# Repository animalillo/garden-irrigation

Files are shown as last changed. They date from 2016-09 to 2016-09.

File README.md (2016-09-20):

#Garden Irrigation Control
This project was created as a fun learning experience for me with PICs (arduino dumilanove) and to solve tiny itch I had about my garden needing to set the analog clock it had to control irrigation times.

I migh or migh not update this project in the future with new features, and I will be creating a side project to control this system from a phone with or without a server web interface to gather the data, that's yet to be seen.

Of course this system  could have many other uses besides irrigation control. Basically any timed electrical switching could be handled with this.
Hacking this code to use the sensor data to perform actions based on the sensor output shoulnd't be too hard. I might do that in the future, or maybe adding an earth humidity sensor and performing actions inresponse to that, i might do that some day.

###Features:
Right now the hardware consists on an arduino, ethernet shield + micro SD card reader, an RTC module that happens to have both, RTC and EEPROM ICs and an humidity sensor that has built-in thermometer.

- It logs the temperature and humidity to an sd file.
- Loads the network configuration from a file called net.cfg on the root of the micro SD card.
- Controls two relays with 4 on-off alarms consisting on an start and end time (HH:MM:SS).
- Exposes a serie of HTTP APIs to the connected network that allows log download, relay control, date and time configuration and instant sensor and status information access.

#Hardware
- Arduino UNO or compatible board
- HanRun Ethernet shield with Micro SD card reader
- I2C RTC module (Tiny RTC) obtained from [here](http://www.dx.com/p/tiny-rtc-real-time-clock-module-for-arduino-red-161172) which consists on:
-- DS1307 RTC chip
-- Atmel AT24C32 EEPROM 32K chip
- Kyees funduino ver: 2R1B relay module from [here](http://www.dx.com/p/arduino-2-channel-relay-shield-module-red-144140)

###Hardware setup:
The ethernet module is simply attached to the arduino board on the standard way.
As some of the pins are used by the ethernet shield, I used the next ones to connect the relay inputs to the arduino digital pins 8 and 9 outputs (IN1 -> digital 9, IN2 - digital 8).
As for the DHT11 (humidity sensor) I used the pin 7.
The I2C RTC clock SDA goes to Arduino analog pin 4 and the SCL goes to arduino analog pin 5 ([if you decide to use another arduino board you should change according to the arduino documentation](https://www.arduino.cc/en/Reference/Wire))

#Configuring network:
To configure the network on the device, you must place a file like the provded net.cfg.example file called net.cfg on the root directory of your sd card.
You must follow the next rules:

	MAC ADDRESS  that will use the device
    IP ADDRESS that will have the device on your network
    NETMASK of the network
    GATEWAY of the network
    DNS SERVER of the network
    
This is an example of a working NET.CFG file:

	DE:AD:BE:EF:FE:ED
	192.168.4.6
	255.255.255.0
	192.168.4.1
	192.168.4.1

#HTTP API
Last, but not least, the HTTP API:
All the date and time API endpoints will use the following format due to hardware limitations and code simplicity:
> YEAR/MONTH/DAY/DAY_OF_WEEK/HOUR/MINUTE/SECOND

- Date
	- **setTime** Configures the RTC clock with the given date and time.
    > 	http://ip_address/setTime/YEAR/MONTH/DAY/DAY_OF_WEEK/HOUR/MINUTE/SECOND

	> Example:
	> http://192.168.4.6/setTime/2016/09/20/2/17/29/30 would set the time and date to tuesday 20th of september of the year 2016 and the time to 17:29:30

	- **getTimes** Prints a plain text dump of the current date and time and the configured alarms.

- Alarms:
	- There is a total of 8 defined alarms, 4 for the each relay. Each alarm consists  on two times in between which the relay will be active, so it's important to **set them both!** There is no specific api to disable an alarm, but if you need to the procedure it's simple: set the start and end time to the same and it shouldn't fire.
	- All the alarm configurations are saved on the EEPROM and persisted in case of power failure.
	- **setAlarm** Configures an alarm.
		- This endpoint has three parameters, the alarm number, the operation type (start/stop) and the time.
		- The date part specified on this api will be ignored, but it's requiered.
	- >		http://ip_address/setAlarm/ALARM_NUMBER(1-8)/ALARM_MODE(start/stop)/DATE_AND_TIME_URL_FORMATTED
	 > Example:
	 > http://192.168.4.6/setAlarm/1/start/2016/09/20/2/17/29/30 **AND another call to** http://192.168.4.6/setAlarm/1/start/2016/09/20/2/19/00/00 would configure an alarm to start everyday at 17:19:30 and stop at 19:00:00

- Direct relay control
	- To control the relays two endpoints are available (sw1 and sw2), both have the same functionality: manually enabling, dissabling and controlling the relays.
	- **sw*X*** Access switch ***X***, replace X with 1 or 2.
		- **on** Turn the relay on.
		- **off** Turn the relay off.
			- **force** Force the relay to stay in off state even if an alarm would fire. This will be saved even after device restart and until the next call to on or off endpoints is made.
    - > Example:
     http://192.168.4.6/sw1/on Would turn the first relay on
     http://192.168.4.6/sw1/off Would turn the first relay off and let alarms fire
     http://192.168.4.6/sw1/off/force Would rutn the first relay off and prevent alarms from turning it on.

- Logs
	- To gather the logs that the system has generated a simple call to /log is needed. Note that the data log will be deleted once the transfer has finished.
	- **log** Get the logs and clear the file
	- The log format is a line containing each measurement, each line is confirmed of the current date and time and the sensors data
	- Example output:
	- 	> <2016-09-20 20:20:10>H:20;T:35;
		> <2016-09-20 20:21:10>H:21;T:34;
	- >		http://ip_address/log

	> Example:
	> http://192.168.4.6/log

- Sensors
	- **getSensors** Prints a simple line containing the sensors information and relay status. The format of the returned text is: sensor:status;other_sensor:status;...
		- **H** is an integer representing the relative humidity
		- **T** is an integer representing the temperature
		- **SW1** and **SW2** is an integer representing the boolean status of the relay 1 and 2

#Case
I made a simple 3D case, but the cap won't stick to the body unless you use tape, if anybody is willing to make a better design it's welcome, just make a merge request.

This case will work with the provided hardware specs, but I can't warrant that it will with another kind of module brands that might be perfectly compatible with this code as I designed it to be quiet a tight fit.
The case has space for a prototyping board and an extra board on top of this, so you can make a pretty circuit and integrate all the components.

I made the case so it's rain resistant, but that will depend on your 3D printer, material and printer configuration. Check the results that come from your printer!

#License
The code is under the [GPL V3](http://www.gnu.org/licenses/gpl.html) license created by Marcos Zuriaga, unless otherwise specified on the files.

The case model is under Creative Commons Attribution-NonCommercial-ShareAlike 4.0 International, also created by Marcos Zuriaga.

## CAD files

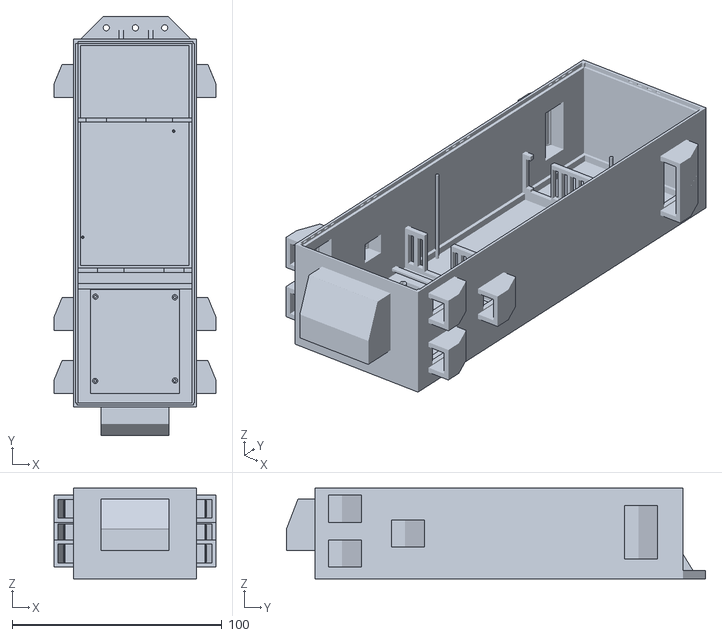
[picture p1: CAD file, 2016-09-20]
Case/garden_irrigation_system_body.stl
77.2 x 200.0 x 43.3

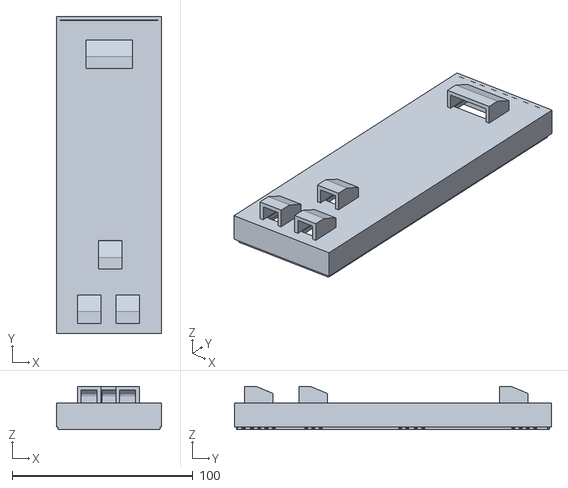
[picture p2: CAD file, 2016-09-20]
Case/garden_irrigation_system_cap.stl
58.4 x 175.5 x 23.9

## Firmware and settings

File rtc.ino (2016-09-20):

/* 
 * File:   DS1307.cpp
 * Version: 1.0
 * Purpose: Controlling relays, making them interact with time and 
 * log some sensor data while exposing some configuration and functions
 * trough the network.
 * License: GPL v3 (http://www.gnu.org/licenses/gpl.html)
 * Author: Marcos Zuriaga Miguel (Created on 04 of July 2016)
 */

/*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
  * You should have received a copy of the GNU General Public License
  * along with this program.  If not, see <http://www.gnu.org/licenses/>.
*/

#include <Wire.h>
#include <SD.h>
#include <Ethernet.h>
#include <avr/pgmspace.h>
#include <stdlib.h>

#include "lib/DHT11/DHT11.h"
#include "lib/DS1307/DS1307.h"
#include "lib/AT24C32_64/AT24C32_64.h"

#define DHT11_PIN 7
#define SW1 9
#define SW2 8

#define ALARM1_START_ADDRESS    0
#define ALARM2_START_ADDRESS    3
#define ALARM3_START_ADDRESS    6
#define ALARM4_START_ADDRESS    9

#define ALARM5_START_ADDRESS    12
#define ALARM6_START_ADDRESS    15
#define ALARM7_START_ADDRESS    18
#define ALARM8_START_ADDRESS    21

#define ALARM1_STOP_ADDRESS     24
#define ALARM2_STOP_ADDRESS     27
#define ALARM3_STOP_ADDRESS     30
#define ALARM4_STOP_ADDRESS     33

#define ALARM5_STOP_ADDRESS     36
#define ALARM6_STOP_ADDRESS     39
#define ALARM7_STOP_ADDRESS     42
#define ALARM8_STOP_ADDRESS     45

#define FORCE_SW1_OFF_ADDRESS   100
#define FORCE_SW2_OFF_ADDRESS   101

DS1307 rtc;
AT24C32_64 rom;

dht11 DHT11;
EthernetServer server(80);
unsigned long last_log = 0;
unsigned long last_tick = 0;
bool force_sw1_on = false;
bool force_sw2_on = false;
bool force_sw1_off = false;
bool force_sw2_off = false;

void setup() {
  Wire.begin();

  Serial.begin(9600);
  
  if (!rtc.isStarted()){
      Serial.println(F("setting up RTC for first boot"));
      startClock();
  }

  if (!SD.begin(4)) {
    Serial.println(F("initialization failed!"));
  }
  
  force_sw1_off = rom.readBool(FORCE_SW1_OFF_ADDRESS);
  force_sw2_off = rom.readBool(FORCE_SW2_OFF_ADDRESS);
  
  pinMode(SW1, OUTPUT);
  pinMode(SW2, OUTPUT);
  
  setupEthernet();
  
  Serial.println(F("ready"));
}

void loop() {
  DateTime t = rtc.getTime();
  while (DHT11.read(DHT11_PIN) != 0) delay(50);

//  DHT11.read(DHT11_PIN);
//  Serial.print(F("humidity:"));
//  Serial.println(DHT11.humidity);
//  Serial.print(F("temperature"));
//  Serial.println(DHT11.temperature);
  
  /*Serial.print(t.hour());Serial.print(":");Serial.print(t.minute());Serial.print(":");Serial.println(t.second());
  Serial.print("Day of the week: "); Serial.println(t.dayOfWeek());
  Serial.print(t.year());Serial.print("-");Serial.print(t.month());Serial.print("-");Serial.println(t.day());
*/
  EthernetClient client = server.available();
  if (client){
    // an http request ends with a blank line
    while (client.connected()) {
      if (client.available()) {
        String method = readLine(&client);
        String line = "";
        while (line.charAt(line.length()-1) != '\n') {
          line = readLine(&client);
          Serial.println(line.c_str());
        }

        Serial.println(method.c_str());
        if (method.indexOf(F("/sw1")) > 0){
          if (method.indexOf(F("/on")) > 0) {
            force_sw1_on = true;
            force_sw1_off = false;
          }

          if (method.indexOf(F("/off")) > 0){
            force_sw1_on = false;
            force_sw1_off = false;

            if (method.indexOf(F("/force")) > 0){
                force_sw1_off = true;
            }
          }
          
          rom.write(force_sw1_off, FORCE_SW1_OFF_ADDRESS);
          
          http_ok_html(&client);

          client.println(method.c_str());
        }
        else if (method.indexOf(F("/sw2")) > 0){
          if (method.indexOf(F("/on")) > 0) {
            force_sw2_on = true;
            force_sw2_off = false;
          }

          if (method.indexOf(F("/off")) > 0){
            force_sw2_on = false;
            force_sw2_off = false;
            
            if (method.indexOf(F("/force")) > 0){
                force_sw2_off = true;
            }
            
          }
          
          rom.write(force_sw2_off, FORCE_SW2_OFF_ADDRESS);
            
          http_ok_html(&client);

          client.println(method.c_str());
        }
        else if (method.indexOf(F("/log")) > 0){
          http_ok_text(&client);
          
          File current_file = SD.open(F("/log/data.log"));
          dump_logs(&client, &current_file);
          current_file.close();
          SD.remove(F("/log/data.log"));
//          printDirectory(f, 0);
        }
        else if (method.indexOf(F("getSensors")) > 0){
            http_ok_text(&client);
            
            client.print(F("H:")); client.print(DHT11.humidity); client.print(F(";")); 
            client.print(F("T:")); client.print(DHT11.temperature); client.print(F(";"));
            client.print(F("SW1:"));client.print(checkSW1(&t));client.print(F(";"));
            client.print(F("SW2:")); client.print(checkSW2(&t)); client.println(F(";"));
        }
        else if (method.indexOf(F("setTime")) > 0){
            http_ok_html(&client);
            
            t = extractUrlDate(&method, method.indexOf(F("setTime")));
            rtc.setTime(t);
        }
        else if (method.indexOf(F("getTimes"))){
            http_ok_text(&client);
            
            client.print(F("Current:")); client.print(t.toString().c_str()); client.println(F(";"));
            
            byte start[3] = {0,0,0};
            byte stop[3] = {0,0,0};

            for (uint8_t i = 0; i < 8; i++){
                rom.readByteArray((byte*)&start, ALARM1_START_ADDRESS + i*3, 3);
                rom.readByteArray((byte*)&stop, ALARM1_STOP_ADDRESS   + i*3, 3);
                
                client.print(F("Alarm")); client.print(i +1); client.print(F(":"));
                for (uint8_t x = 0; x < 3; x++){
                    client.print(start[x]); //client.print(F(":")); client.print(start[1]); client.print(F(":")); client.print(start[2]);
                    if (x < 2) client.print(F(":"));
                }
                client.print(F(","));
                for (uint8_t x = 0; x < 3; x++){
                    client.print(stop[x]); //client.print(stop[0]); client.print(F(":")); client.print(stop[1]); client.print(F(":")); client.print(stop[2]);
                    if (x < 2) client.print(F(":"));
                }
                
                client.println(F(";"));
            }
        }
        else if (method.indexOf(F("setAlarm")) > 0){
            http_ok_html(&client);
            
            if (method.indexOf(F("start")) > 0){
                int tmp = method.indexOf(F("/start"));
                char c[1] = {' '};
                
                t = extractUrlDate(&method, tmp+1);
                
                c[0] = method[tmp -1];
                tmp = atoi(c);
                
                tmp = atoi(c);
                
                setAlarm(&t, ALARM1_START_ADDRESS + 3*(tmp-1));
            }
            
            if (method.indexOf(F("stop")) > 0){
                int tmp = method.indexOf(F("/stop"));
                char c[2] = {' '};
                
                t = extractUrlDate(&method, tmp+1);
                c[0] = method[tmp -1];

                tmp = atoi(c);

                setAlarm(&t, ALARM1_STOP_ADDRESS + 3*(tmp-1));
            }
        }
        else {
            http_ok_html(&client);
        }
        
        
          delay(1);
          client.stop();
      }
    }
  }
  
  t = rtc.getTime();
  
  if (millis() - last_tick >= 1000){
//      Serial.print(t.hour());Serial.print(F(":"));Serial.print(t.minute());Serial.print(F(":"));Serial.println(t.second());
//      if(force_sw1_off) Serial.println(F("SW1 off forced"));
      
      switch1(checkSW1(&t));
      switch2(checkSW2(&t));
      
      last_tick = millis();
  }

  // Log each minute
  if (millis() - last_log  >= 60000){

    String dir = F("/log");
    if (SD.mkdir(dir)){
      File current_file;
      dir += F("/data.log");
      current_file = SD.open(dir, FILE_WRITE);

      current_file.print(F("<")); current_file.print(t.toString().c_str()); current_file.print(F(">")); 
      current_file.print(F("H:")); current_file.print(DHT11.humidity); current_file.print(F(";")); 
      current_file.print(F("T:")); current_file.print(DHT11.temperature); current_file.println(F(";"));
      current_file.close();
      
      last_log = millis();
    }
  }
}

bool checkSW1(DateTime* t) {
    return (!force_sw1_off && fireAlarm(t, ALARM1_START_ADDRESS, ALARM1_STOP_ADDRESS, 4)) || force_sw1_on;
}
bool checkSW2(DateTime* t) {
    return (!force_sw2_off && fireAlarm(t, ALARM5_START_ADDRESS, ALARM5_STOP_ADDRESS, 4)) || force_sw2_on;
}

void http_ok(EthernetClient* client){
    client->println(F("HTTP/1.1 200 OK"));
}

void http_ok_html(EthernetClient* client){
    http_ok(client);
    client->println(F("Content-Type: text/html"));
    client->println();
}

void http_ok_text(EthernetClient* client){
    http_ok(client);
    client->println(F("Content-Type: text/plain"));
    client->println();
}

void dump_logs(EthernetClient* client, File* cf){
    while (true) {
       char c = cf->read();
       if (c == -1) break;
       client->print(c);
    }
}

void setAlarm(DateTime* t, uint16_t address){
    byte time[3] = {t->hour(), t->minute(), t->second()};
//    Serial.print(F("Setting alarm: ")); Serial.println(address);
//    Serial.print(time[0]); Serial.print(F(":")); Serial.print(time[1]); Serial.print(F(":")); Serial.println(time[2]);
    rom.write((byte *)&time, (uint8_t)3, address);
}

bool fireAlarm(DateTime* t, uint16_t alarm_start_address, uint16_t alarm_end_address, uint8_t hops){
    byte start[3] = {0,0,0};
    byte stop[3] = {0,0,0};
    
    for (uint8_t i = 0; i < hops; i++){
        rom.readByteArray((byte*)&start, alarm_start_address + i*3, 3);
        rom.readByteArray((byte*)&stop, alarm_end_address    + i*3, 3);
        
        if (t->hour() >= start[0] && t->hour() < stop[0]){
            return true;
        }
        else if (t->hour() == stop[0]){
            if (t->minute() < stop[1]){
                return true;
            }
            else if(t->minute() == stop[1]){
                if (t->second() <= stop[2]) return true;
            }
        }
            
            
    }
//        Serial.print("Alarm "); Serial.print(ALARM1_START_ADDRESS + i*3); Serial.print("+"); Serial.print(ALARM1_STOP_ADDRESS  + i*3); Serial.println(" Fired");
//        Serial.print(start[0]); Serial.print(F(":")); Serial.print(start[1]); Serial.print(F(":")); Serial.println(start[2]);
//        Serial.print(stop[0]); Serial.print(F(":")); Serial.print(stop[1]); Serial.print(F(":")); Serial.println(stop[2]);
    return false;
}

DateTime extractUrlDate(String* date_url, int start){
    start = date_url->indexOf('/', start + 1) + 1;
    
    uint8_t ct = 0;
    uint8_t type = 0;
    uint16_t tmp_number = 0;
    char buff[4] = {0,0,0,0};
    char c = ' ';
    
    DateTime dt = DateTime(18, 30, 40, 6, 28, 8, 2016);
    while (true) {
        if (type > 6) break;
        
        c = date_url->charAt(start);
        if (c == '/') {
            tmp_number = atoi(buff);
            
            switch(type){
                case 0:
                    dt.setYear(tmp_number);
                    break;
                case 1:
                    dt.setMonth(tmp_number);
                    break;
                case 2:
                    dt.setDay(tmp_number);
                    break;
                case 3:
                    dt.setDayOfWeek(tmp_number);
                    break;
                case 4:
                    dt.setHour(tmp_number);
                    break;
                case 5:
                    dt.setMinute(tmp_number);
                    break;
                case 6:
                    dt.setSecond(tmp_number);
                    break;
            }
            type ++;
            ct = 0;
            tmp_number = 0;
            for (byte i = 0; i < 4; i++) buff[i] = 0;
        }
        else {
            buff[ct] = c;
            ct ++;
        }
        
        start ++;
        //if ()
    }
    
    return dt;
}

void switch1(bool status){
  digitalWrite(SW1, (status) ? HIGH : LOW);
}

void switch2(bool status){
    digitalWrite(SW2, status);
}

String readLine(EthernetClient* client){
  String rturn = "";
  while(client->connected()){
    if (client->available()){
      char c = client->read();
      rturn += c;
      if (c == '\n'){
        return rturn;
      }
    }
  }
  return rturn;
}

void startClock(){
    DateTime dt = DateTime(18, 30, 40, 6, 28, 8, 2016);
    rtc.setTime(dt);
}

void setupEthernet(){
  if (SD.exists(F("/NET.CFG"))){
    char c = ' ';
    
    byte mac[6] = {0,0,0,0,0,0};
    byte ip[4] = {0,0,0,0}, netmask[4] = {0,0,0,0}, gateway[4] = {0,0,0,0}, dns[4] = {0,0,0,0};
    
    File current_file = SD.open(F("/NET.CFG"), FILE_READ);

    // Order of the calls is important!
    getMac(&current_file, mac);
    getIP(&current_file, ip);
    getIP(&current_file, netmask);
    getIP(&current_file, gateway);
    getIP(&current_file, dns);

//    Serial.print(F("MAC: "));Serial.print(mac[0], HEX);Serial.print(":");Serial.print(mac[1], HEX);Serial.print(":");Serial.print(mac[2], HEX);Serial.print(":");Serial.print(mac[3], HEX);Serial.print(":");Serial.print(mac[4], HEX);Serial.print(":");Serial.println(mac[5], HEX);
//    Serial.print(F("IP: "));Serial.print(ip[0]);Serial.print(".");Serial.print(ip[1]);Serial.print(".");Serial.print(ip[2]);Serial.print(".");Serial.println(ip[3]);
//    Serial.print(F("netmask: "));Serial.print(netmask[0]);Serial.print(".");Serial.print(netmask[1]);Serial.print(".");Serial.print(netmask[2]);Serial.print(".");Serial.println(netmask[3]);
//    Serial.print(F("dns: "));Serial.print(dns[0]);Serial.print(".");Serial.print(dns[1]);Serial.print(".");Serial.print(dns[2]);Serial.print(".");Serial.println(dns[3]);
//    Serial.print(F("gateway: "));Serial.print(gateway[0]);Serial.print(".");Serial.print(gateway[1]);Serial.print(".");Serial.print(gateway[2]);Serial.print(".");Serial.println(gateway[3]);
    
    Ethernet.begin(mac, ip, dns, gateway, netmask);
    server.begin();
  }
  else {
    //Serial.println("file not found"); Serial.println(F("/NET.CFG"));
    // TODO: store network config and load it from rom as fallback?
  }
}

void getIP(File* cf, byte* ip){
  char c = ' ';
  char buff[3] = {0,0,0};
  
  uint8_t ct = 0;
  uint8_t ct_data = 0;
  while (c != '\n') {
    c = cf->read();

    if (ct_data < 4) {
      // If it's not a net separator (.) or a newline, set the buffer
      if (c != '.' && c != '\n'){
        buff[ct] = c;
        ct++;
      }
      else {
        // Skip this byte and set counters
        ip[ct_data] = atoi(buff);

        ct = 0;
        ct_data++;

        for (byte i = 0; i < 3; i++) buff[i] = 0;
      }
    }
    else {
      cf->read();
    }
  }
}

void getMac(File* cf, byte* mac){
  char c = ' ';
  
  uint8_t ct = 2, ct_data = 0;
  
  while (c != '\n'){
    c = cf->read();
    
    if (ct_data < 6) {
      // If it's not a mac separator (:) or a newline, calculate the mac byte
      if (c != ':' && c != '\n'){
        ct--;
        mac[ct_data] |= getVal(c) << ct*4;
      }
      else {
        // Skip this byte and set counters
        ct = 2;
        ct_data++;
      }
    }
    else{
      cf->read();
    }
  }
}

byte getVal(char c)
{
   if(c >= '0' && c <= '9')
     return (byte)(c - '0');
   else
     return (byte)(c-'A'+10);
}

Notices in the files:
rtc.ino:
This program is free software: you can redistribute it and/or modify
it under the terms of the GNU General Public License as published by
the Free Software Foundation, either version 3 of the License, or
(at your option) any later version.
